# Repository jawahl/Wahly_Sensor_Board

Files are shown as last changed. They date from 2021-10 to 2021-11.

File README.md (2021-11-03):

# Wahly_Sensor_Board

**Hardware Overview**:

This board is designed around the STM32F3 microcontroller, LIS3DHTR accelerometer, and SHT30 temperature & humidity sensor. USB powered, SWD debug/programming, footprint for additional FLASH memory chip (SOIC-8), ADC/TIM pin header breakouts for external peripherals. 

Schematic and layout done in KiCAD, assembly/fab done with JLCPCB.

# Repository Definition:

**Wahly_KiCAD** - Contains all KiCAD project files. Includes schematic (with pdf viewable) and layout files.

**Firmware** - Contains all firmware files for the Wahly Sensor Board. Includes STM32CubeIDE .ioc file with all necessary driver/HAL/main C files.

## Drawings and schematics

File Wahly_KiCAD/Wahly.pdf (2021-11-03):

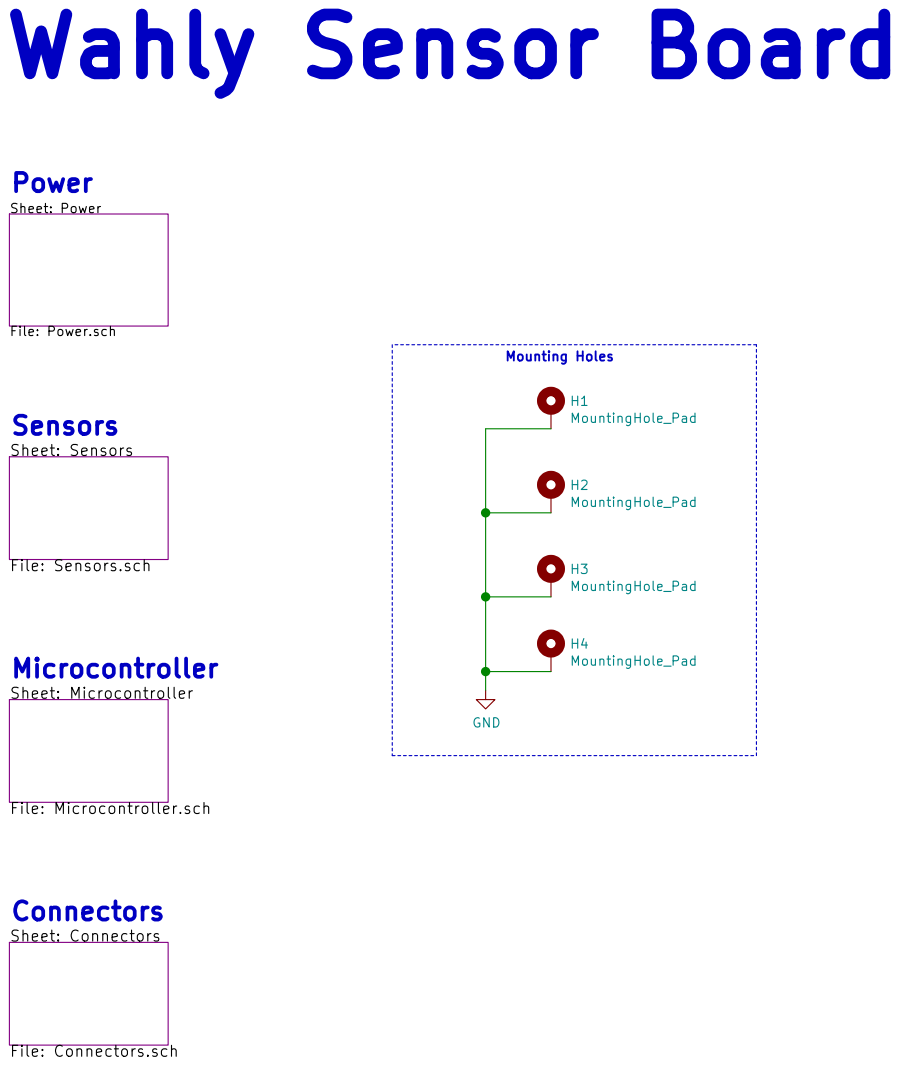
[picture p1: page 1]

Power
Sheet: Sensors File: Sensors.sch Sheet: Microcontroller File: Microcontroller.sch Sheet: Connectors File: Connectors.sch

File: Wahly.sch Sheet: /
Id: 1/5 Title: Wahly Sensor Board - STM32

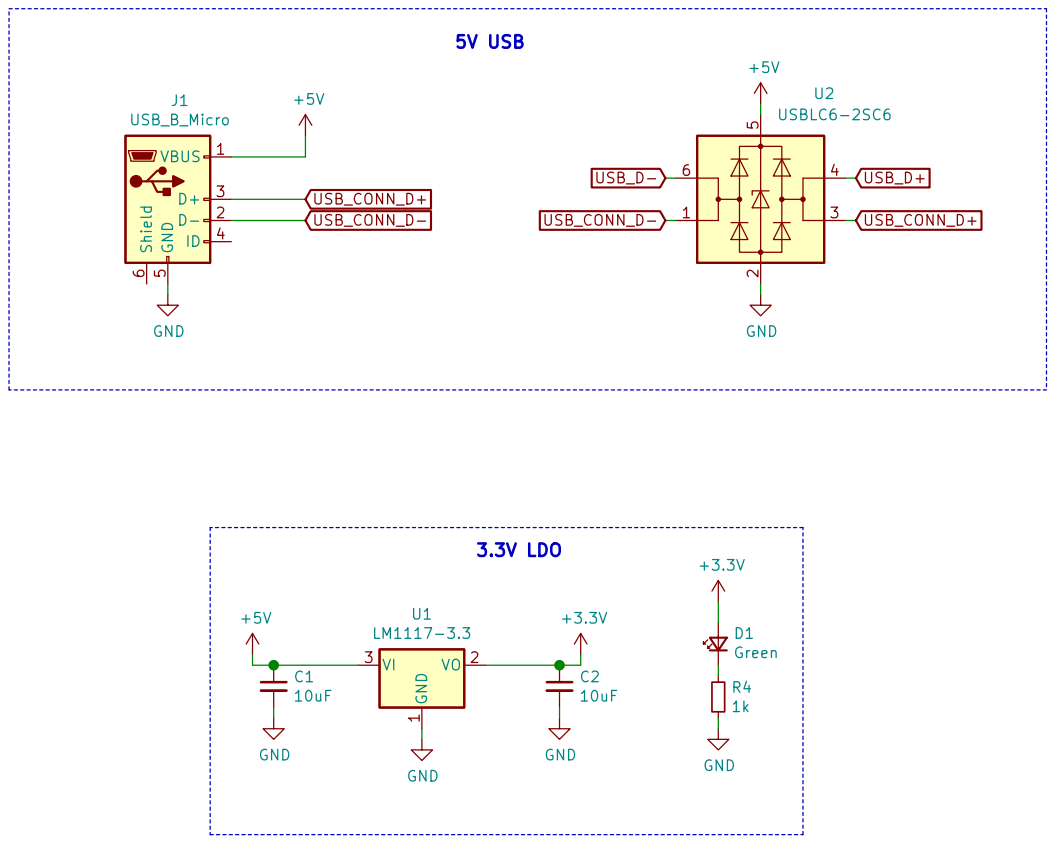
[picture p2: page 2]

File: Power.sch Sheet: /Power/ GND

Id: 2/5 Title: Wahly Sensor Board - STM32

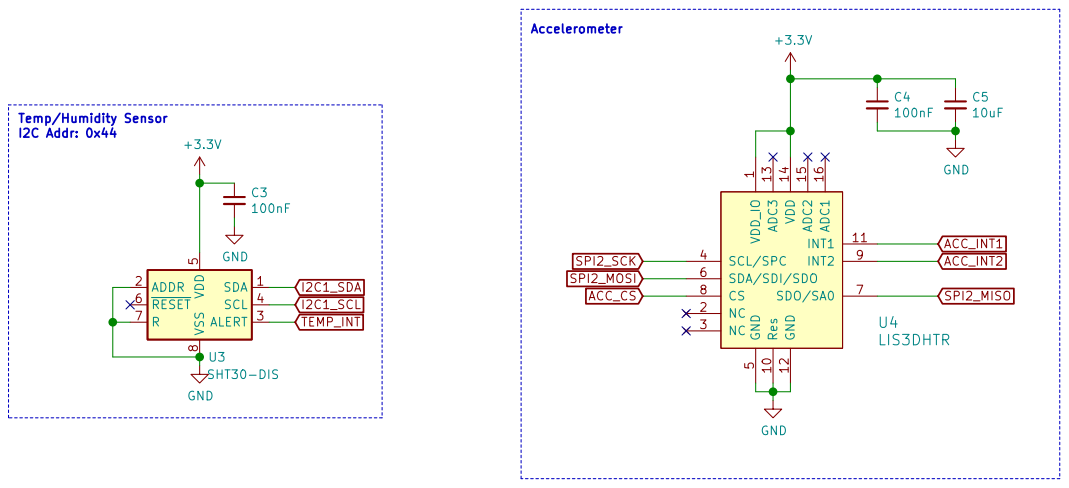
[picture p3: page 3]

1 NC 2 NC 3 SCL/SPC 4 GND

5 SDA/SDI/SDO 6 SDO/SA0 7 CS 8

File: Sensors.sch Sheet: /Sensors/ GND

Id: 3/5 Title: Wahly Sensor Board - STM32

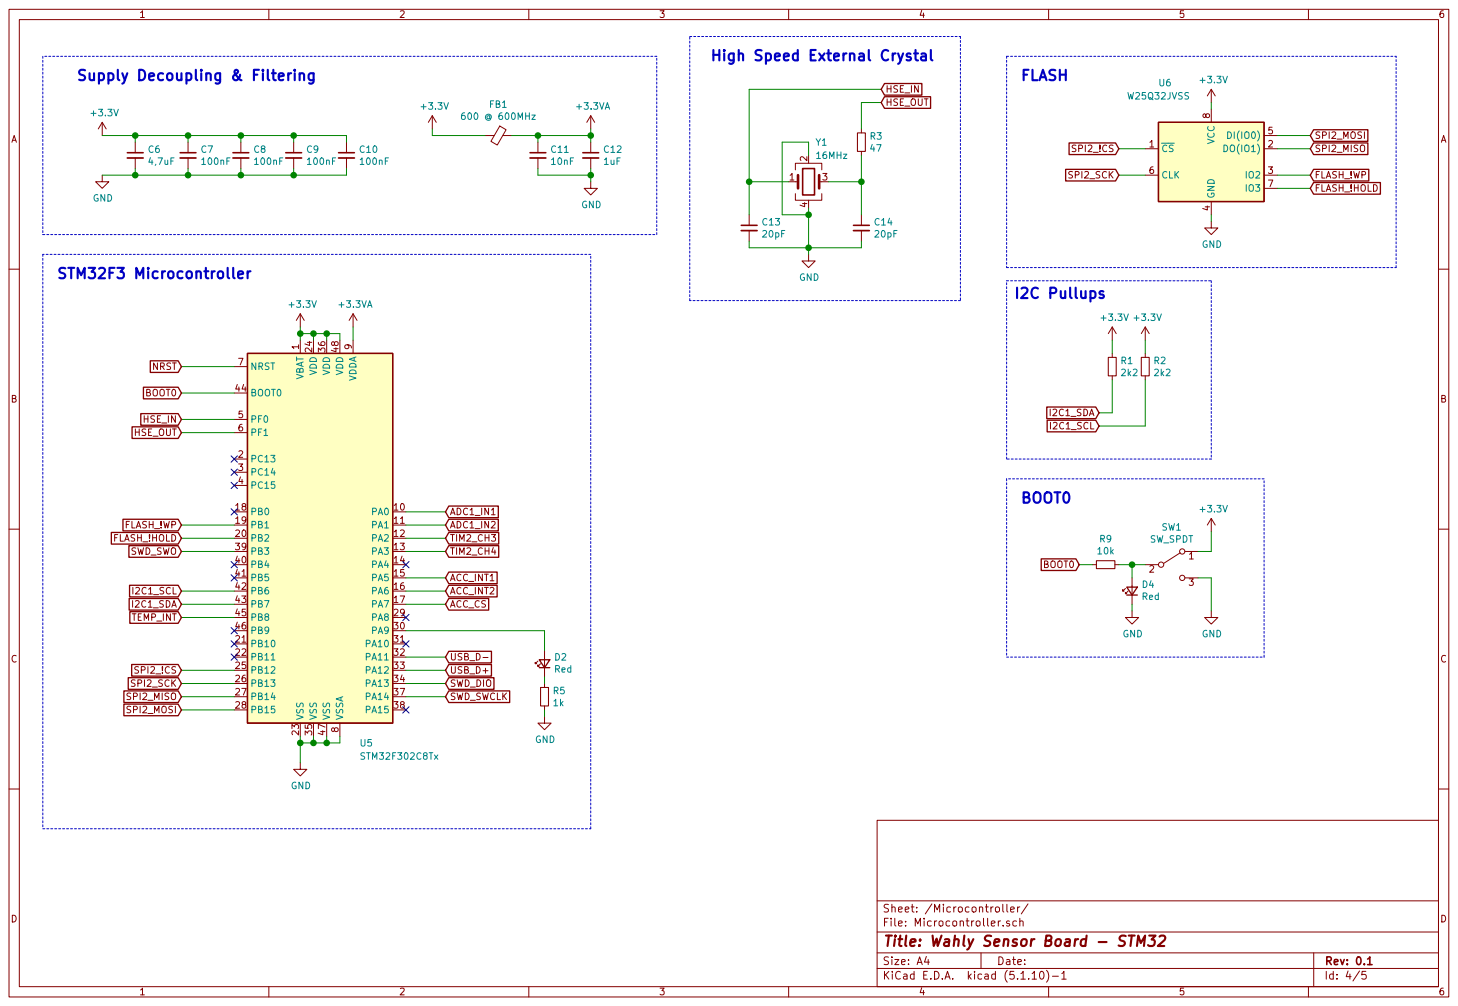
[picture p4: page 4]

High Speed External Crystal

1 VDD 24 VDD 36 VDD 48 VDDA

9 VSS 23 VSS 35 VSS 47 VSSA

File: Microcontroller.sch Sheet: /Microcontroller/
Id: 4/5 Title: Wahly Sensor Board - STM32

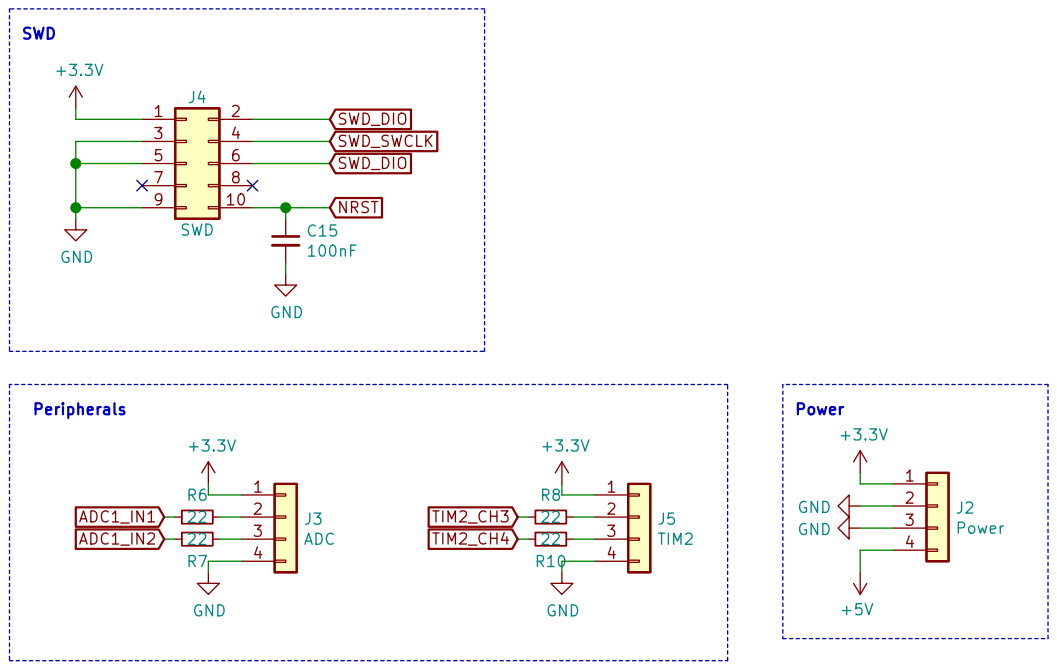
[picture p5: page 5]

File: Connectors.sch Sheet: /Connectors/
Id: 5/5 Title: Wahly Sensor Board - STM32

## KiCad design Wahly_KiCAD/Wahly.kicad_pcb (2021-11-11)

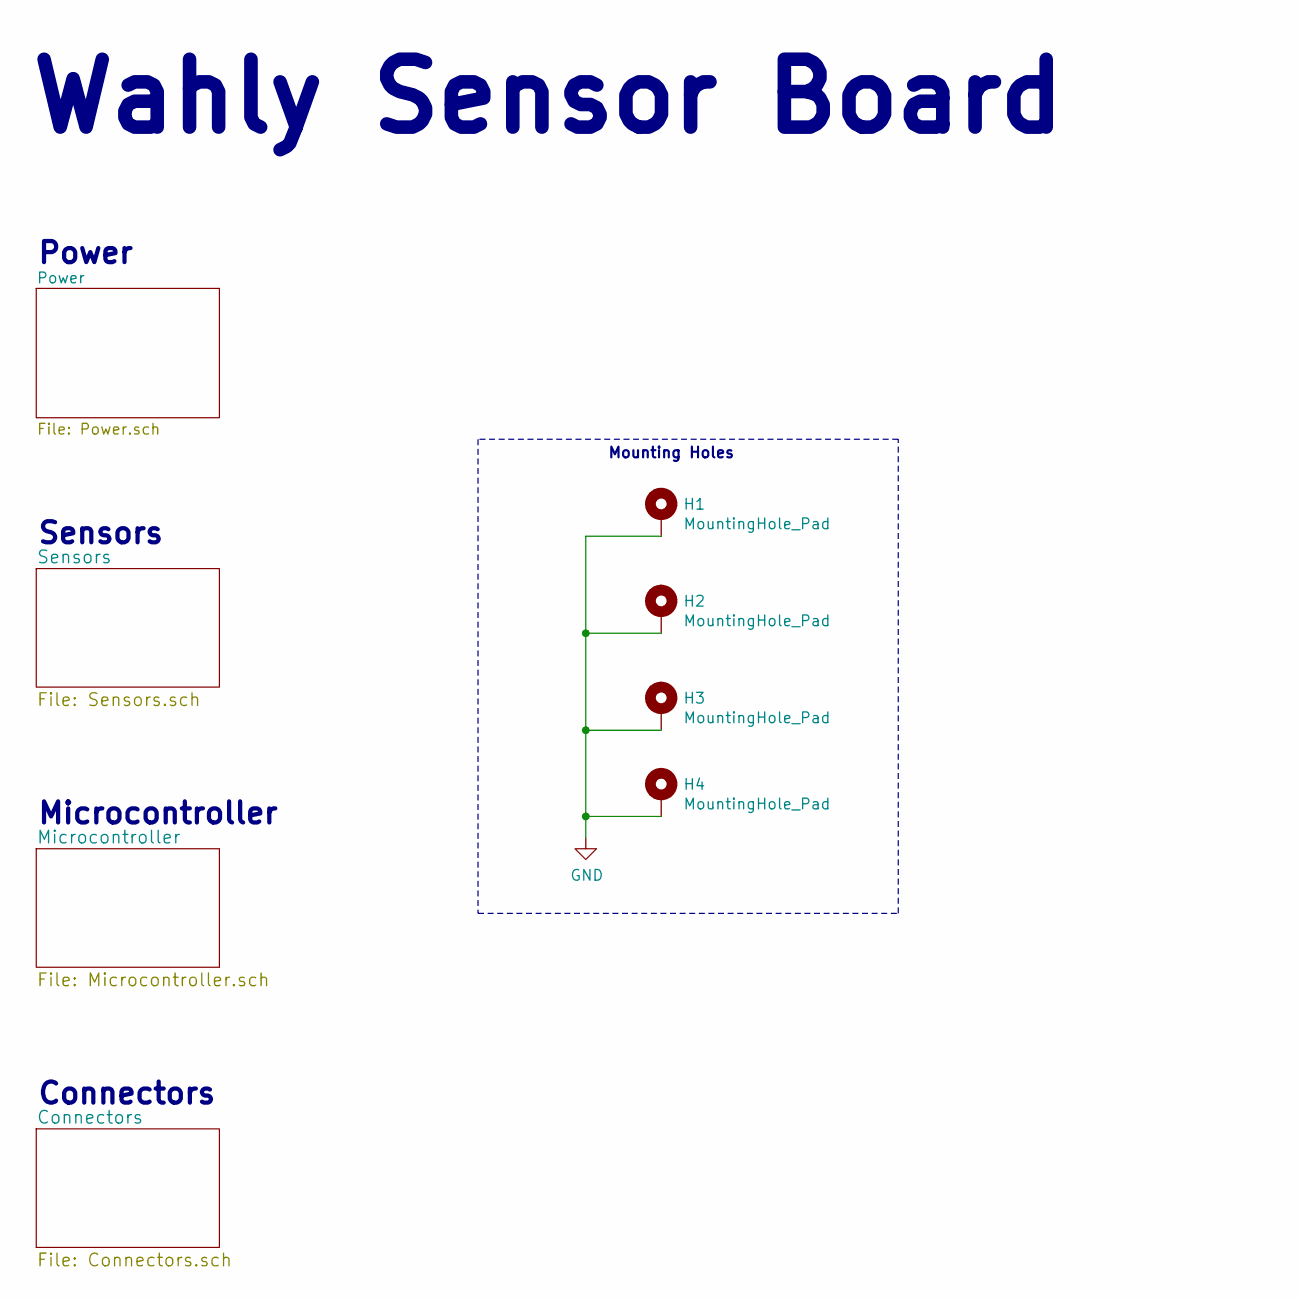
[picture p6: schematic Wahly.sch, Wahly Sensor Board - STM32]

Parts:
H1, H2, H3, H4: MountingHole_Pad; MountingHole_4.3mm_M4_Pad_Via

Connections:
GND: H1.1, H2.1, H3.1, H4.1; also elsewhere on the board

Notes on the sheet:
Wahly Sensor Board
Power
Sensors
Microcontroller
Connectors
Mounting Holes

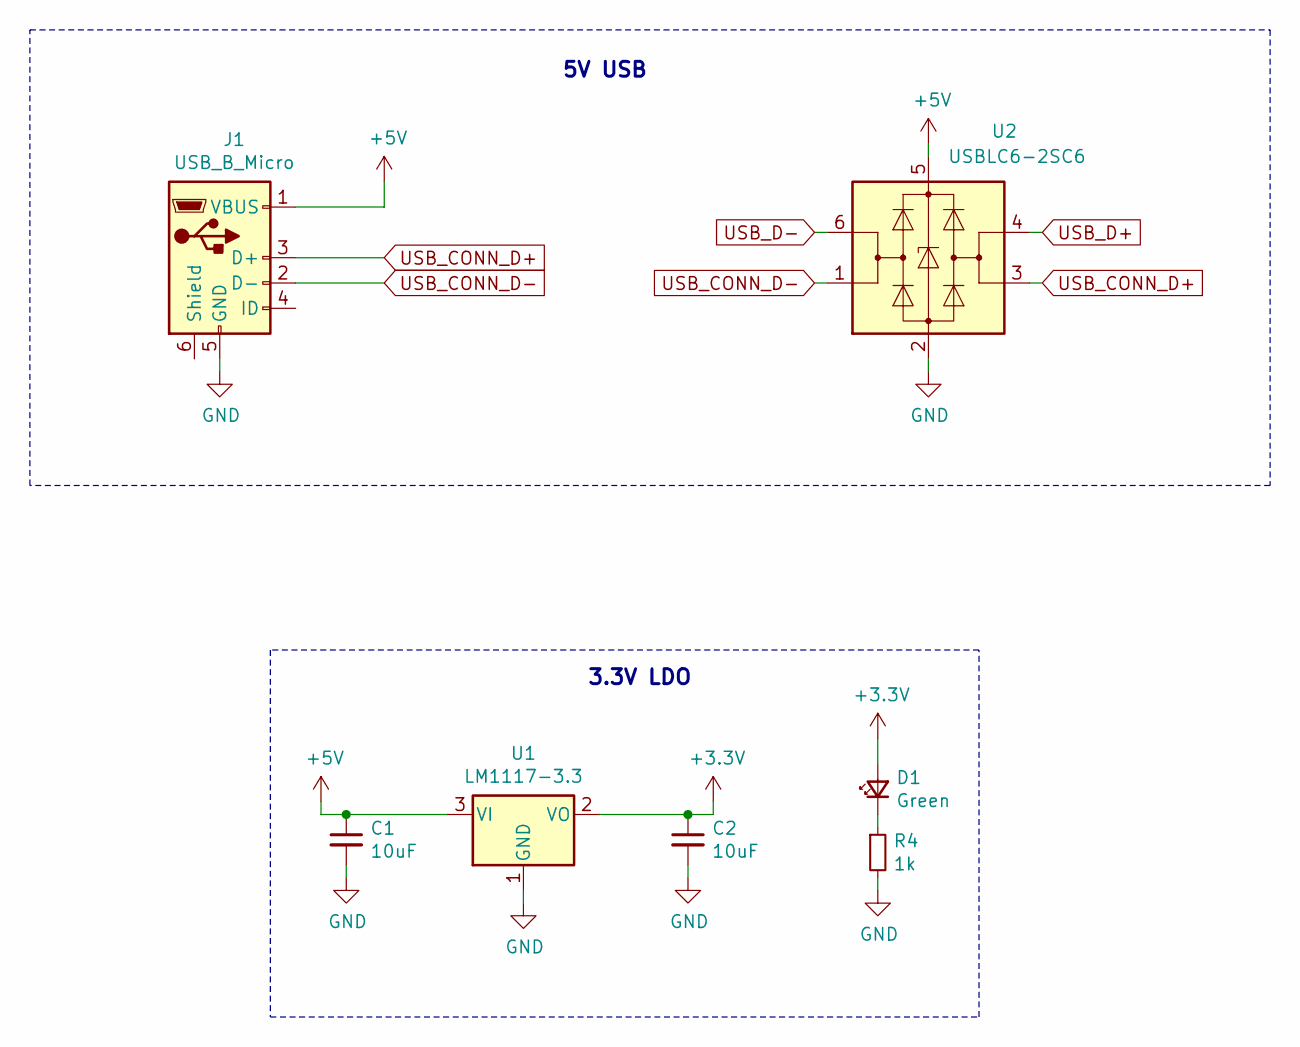
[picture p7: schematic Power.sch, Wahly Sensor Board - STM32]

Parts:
C1, C2: 10uF; C_0402_1005Metric
D1: Green; LED_0603_1608Metric
J1: USB_B_Micro; USB_Micro-B_Molex-105017-0001
R4: 1k; R_0402_1005Metric
U1: LM1117-3.3; SOT-223
U2: USBLC6-2SC6; SOT-23-6

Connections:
+3V3: C2.1, D1.2 (A), U1.2 (VO); also elsewhere on the board
+5V: C1.1, J1.1 (VBUS), U1.3 (VI), U2.5 (VBUS); also elsewhere on the board
GND: C1.2, C2.2, J1.5 (GND), R4.2, U1.1 (GND), U2.2 (GND); also elsewhere on the board
unnamed: D1.1 (K), R4.1
USB_CONN_D+: J1.3 (D+), U2.3 (I/O2)
USB_CONN_D-: J1.2 (D-), U2.1 (I/O1)
USB_D+: U2.4 (I/O2); also elsewhere on the board
USB_D-: U2.6 (I/O1); also elsewhere on the board

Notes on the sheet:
5V USB
3.3V LDO

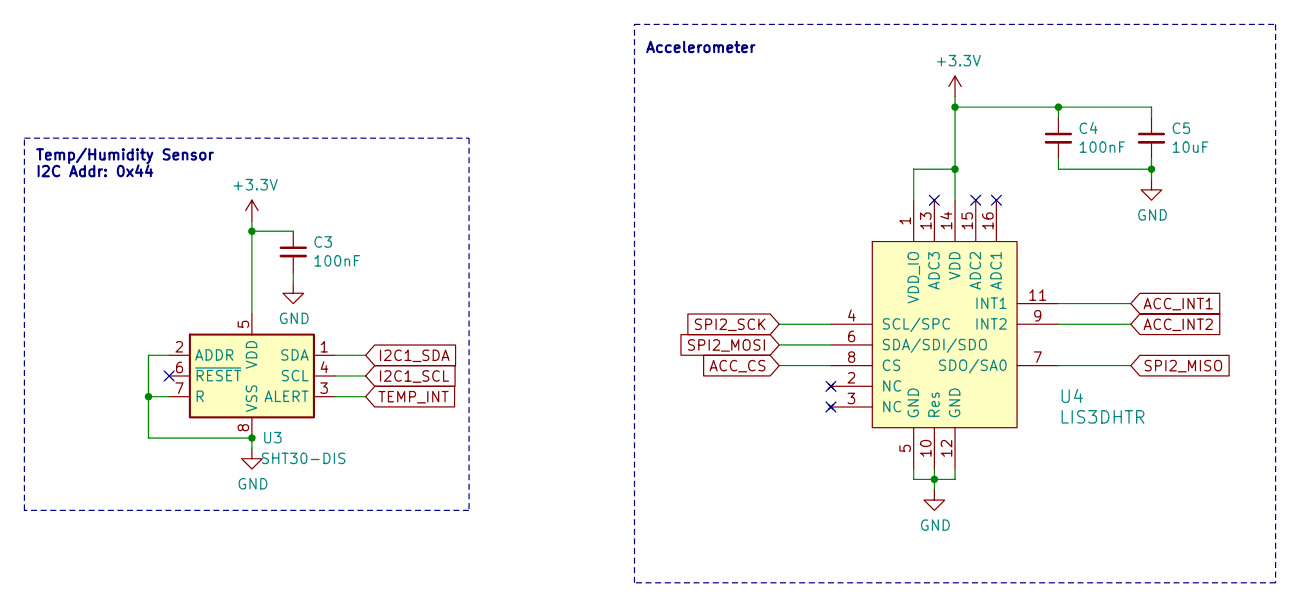
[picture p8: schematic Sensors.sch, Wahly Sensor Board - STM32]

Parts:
C3, C4: 100nF; C_0402_1005Metric
C5: 10uF; C_0402_1005Metric
U3: SHT30-DIS; Sensirion_DFN-8-1EP_2.5x2.5mm_P0.5mm_EP1.1x1.7mm
U4: LIS3DHTR; LGA-16_3x3mm_P0.5mm; MPN LIS3DHTR; Digi-Key_PN 497-10613-1-ND

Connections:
+3V3: C3.1, C4.1, C5.1, U3.5 (VDD), U4.1 (VDD_IO), U4.14 (VDD); also elsewhere on the board
ACC_CS: U4.8 (CS); also elsewhere on the board
ACC_INT1: U4.11 (INT1); also elsewhere on the board
ACC_INT2: U4.9 (INT2); also elsewhere on the board
GND: C3.2, C4.2, C5.2, U3.2 (ADDR), U3.7 (R), U3.8 (VSS), U3.9 (VSS), U4.5 (GND), U4.10 (Res), U4.12 (GND); also elsewhere on the board
I2C1_SCL: U3.4 (SCL); also elsewhere on the board
I2C1_SDA: U3.1 (SDA); also elsewhere on the board
SPI2_MISO: U4.7 (SDO/SA0); also elsewhere on the board
SPI2_MOSI: U4.6 (SDA/SDI/SDO); also elsewhere on the board
SPI2_SCK: U4.4 (SCL/SPC); also elsewhere on the board
TEMP_INT: U3.3 (ALERT); also elsewhere on the board

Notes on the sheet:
Temp/Humidity Sensor I2C Addr: 0x44
Accelerometer

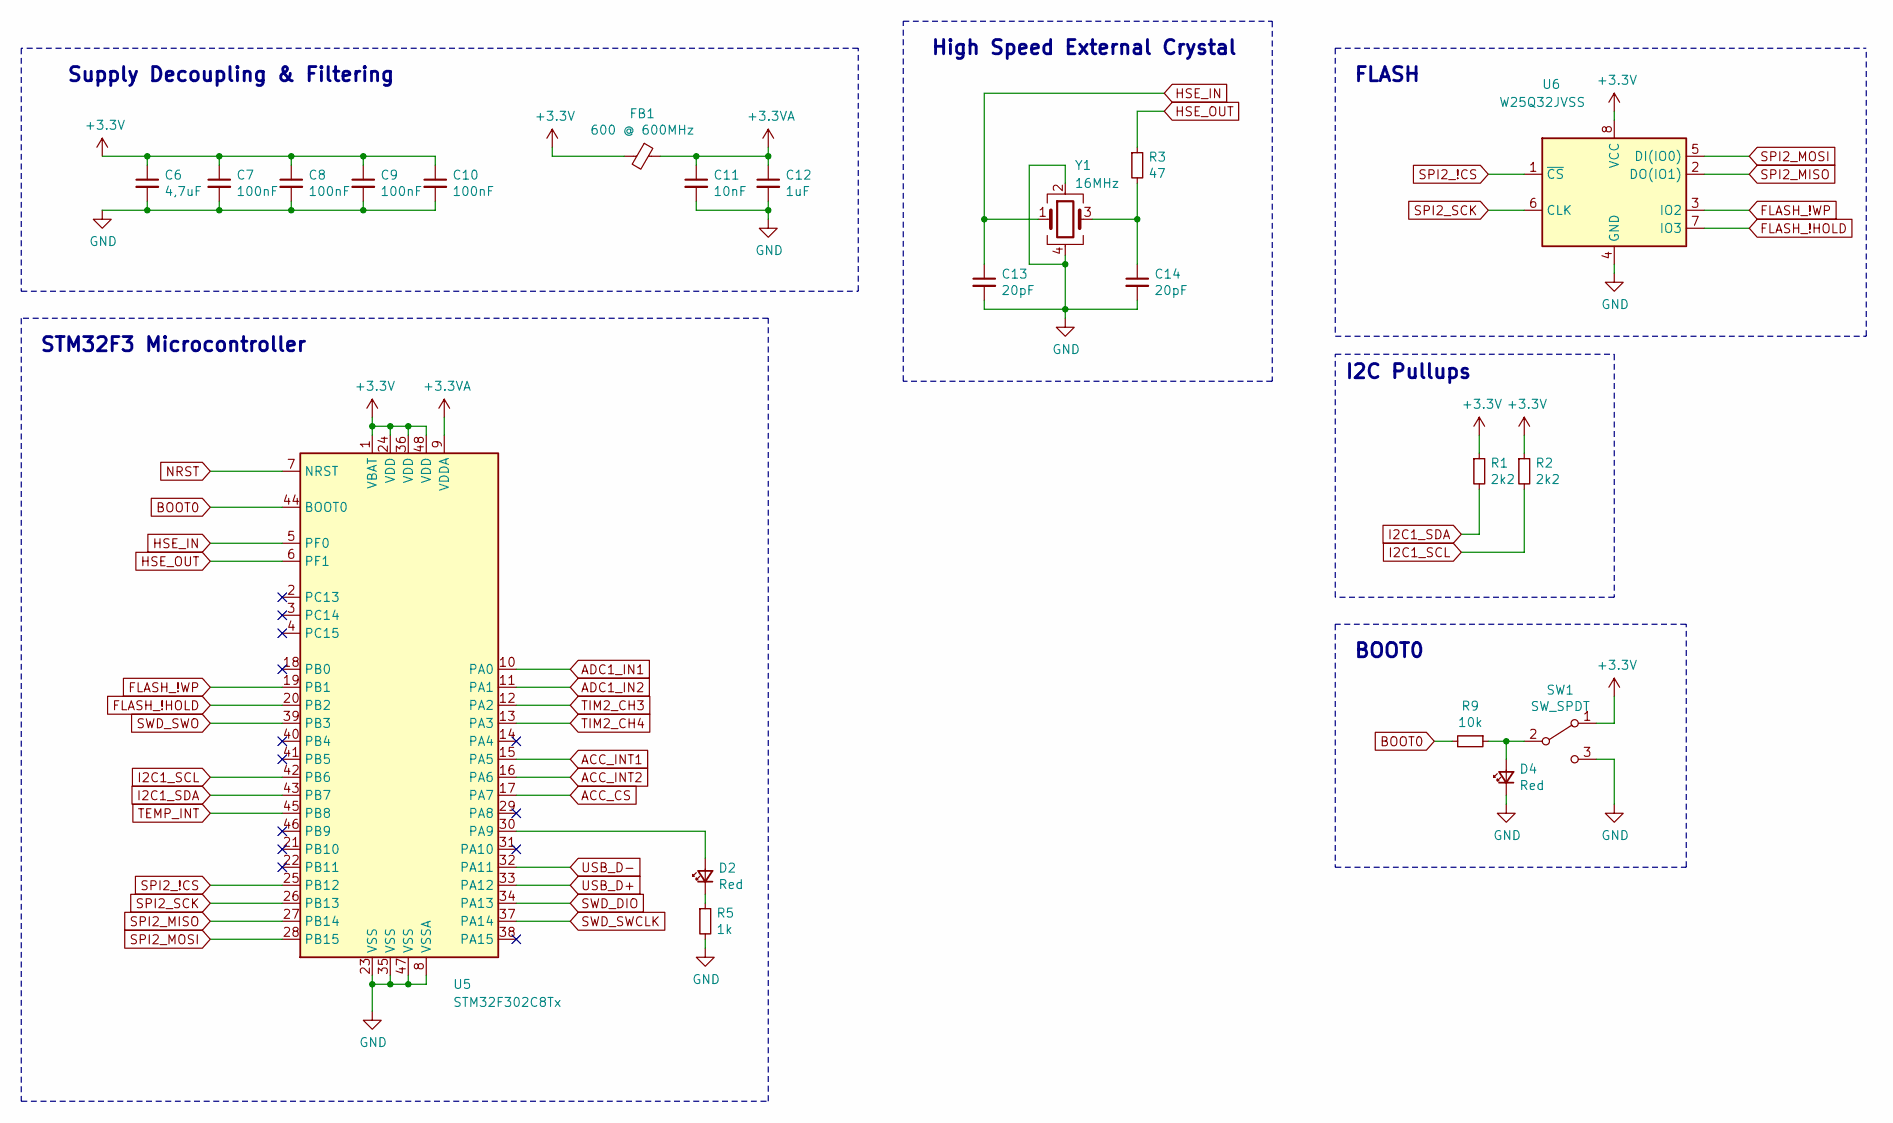
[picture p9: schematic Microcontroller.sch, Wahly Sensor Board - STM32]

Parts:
C6: 4,7uF; C_0402_1005Metric
C7, C8, C9, C10: 100nF; C_0402_1005Metric
C11: 10nF; C_0402_1005Metric
C12: 1uF; C_0402_1005Metric
C13, C14: 20pF; C_0402_1005Metric
D2, D4: Red; LED_0603_1608Metric
FB1: 600 @ 600MHz; L_0603_1608Metric
R1, R2: 2k2; R_0603_1608Metric
R3: 47; R_0402_1005Metric
R5: 1k; R_0402_1005Metric
R9: 10k; R_0603_1608Metric
SW1: SW_SPDT; SW_SPDT_PCM12
U5: STM32F302C8Tx; LQFP-48_7x7mm_P0.5mm
U6: W25Q32JVSS; SOIC-8_5.23x5.23mm_P1.27mm
Y1: 16MHz; Crystal_SMD_TXC_7M-4Pin_3.2x2.5mm

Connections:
+3.3VA: C11.1, C12.1, FB1.1, U5.9 (VDDA)
+3V3: C6.1, C7.1, C8.1, C9.1, C10.1, FB1.2, R1.1, R2.1, SW1.1 (A), U5.1 (VBAT), U5.24 (VDD), U5.36 (VDD), U5.48 (VDD), U6.8 (VCC); also elsewhere on the board
ACC_CS: U5.17 (PA7); also elsewhere on the board
ACC_INT1: U5.15 (PA5); also elsewhere on the board
ACC_INT2: U5.16 (PA6); also elsewhere on the board
ADC1_IN1: U5.10 (PA0); also elsewhere on the board
ADC1_IN2: U5.11 (PA1); also elsewhere on the board
BOOT0: R9.2, U5.44 (BOOT0)
FLASH_!HOLD: U5.20 (PB2), U6.7 (IO3)
FLASH_!WP: U5.19 (PB1), U6.3 (IO2)
GND: C6.2, C7.2, C8.2, C9.2, C10.2, C11.2, C12.2, C13.2, C14.2, D4.1 (K), R5.2, SW1.3 (C), U5.8 (VSSA), U5.23 (VSS), U5.35 (VSS), U5.47 (VSS), U6.4 (GND), Y1.2, Y1.4; also elsewhere on the board
HSE_IN: C13.1, U5.5 (PF0), Y1.1
HSE_OUT: R3.1, U5.6 (PF1)
I2C1_SCL: R2.2, U5.42 (PB6); also elsewhere on the board
I2C1_SDA: R1.2, U5.43 (PB7); also elsewhere on the board
NRST: U5.7 (NRST); also elsewhere on the board
unnamed: C14.1, R3.2, Y1.3
unnamed: D2.1 (K), R5.1
unnamed: D2.2 (A), U5.30 (PA9)
unnamed: D4.2 (A), R9.1, SW1.2 (B)
SPI2_!CS: U5.25 (PB12), U6.1 (~CS)
SPI2_MISO: U5.27 (PB14), U6.2 (DO(IO1)); also elsewhere on the board
SPI2_MOSI: U5.28 (PB15), U6.5 (DI(IO0)); also elsewhere on the board
SPI2_SCK: U5.26 (PB13), U6.6 (CLK); also elsewhere on the board
SWD_DIO: U5.34 (PA13); also elsewhere on the board
SWD_SWCLK: U5.37 (PA14); also elsewhere on the board
SWD_SWO: U5.39 (PB3); also elsewhere on the board
TEMP_INT: U5.45 (PB8); also elsewhere on the board
TIM2_CH3: U5.12 (PA2); also elsewhere on the board
TIM2_CH4: U5.13 (PA3); also elsewhere on the board
USB_D+: U5.33 (PA12); also elsewhere on the board
USB_D-: U5.32 (PA11); also elsewhere on the board

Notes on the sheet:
Supply Decoupling & Filtering
High Speed External Crystal
I2C Pullups
STM32F3 Microcontroller
BOOT0
FLASH

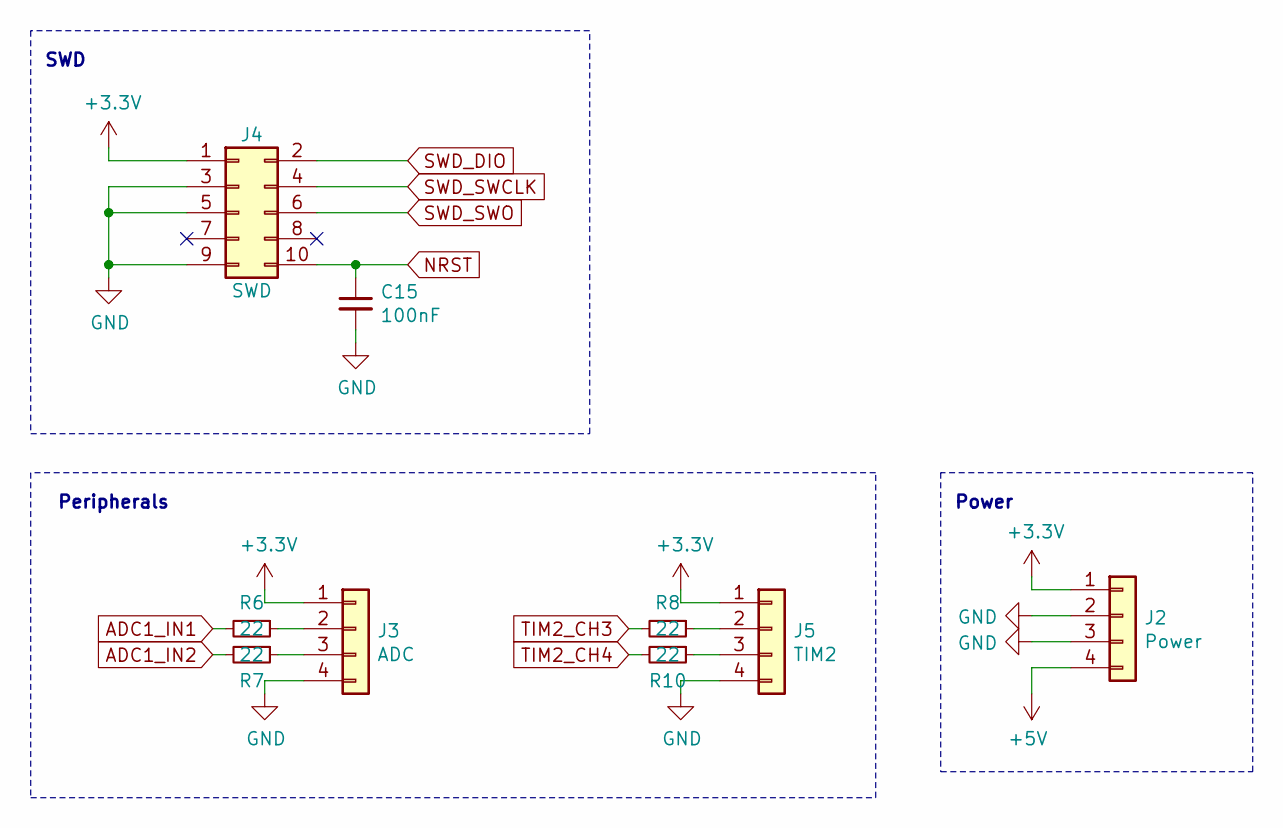
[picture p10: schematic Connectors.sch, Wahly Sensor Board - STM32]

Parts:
C15: 100nF; C_0402_1005Metric
J2: Power; PinHeader_1x04_P2.54mm_Vertical
J3: ADC; PinHeader_1x04_P2.54mm_Vertical
J4: SWD; PinHeader_2x05_P1.27mm_Vertical_SMD
J5: TIM2; PinHeader_1x04_P2.54mm_Vertical
R6, R7, R8, R10: 22; R_0603_1608Metric

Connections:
+3V3: J2.1, J3.1, J4.1, J5.1; also elsewhere on the board
+5V: J2.4; also elsewhere on the board
ADC1_IN1: R6.2; also elsewhere on the board
ADC1_IN2: R7.2; also elsewhere on the board
GND: C15.2, J2.2, J2.3, J3.4, J4.3, J4.5, J4.9, J5.4; also elsewhere on the board
NRST: C15.1, J4.10; also elsewhere on the board
unnamed: J3.2, R6.1
unnamed: J3.3, R7.1
unnamed: J5.2, R8.1
unnamed: J5.3, R10.1
SWD_DIO: J4.2; also elsewhere on the board
SWD_SWCLK: J4.4; also elsewhere on the board
SWD_SWO: J4.6; also elsewhere on the board
TIM2_CH3: R8.2; also elsewhere on the board
TIM2_CH4: R10.2; also elsewhere on the board

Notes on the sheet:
Peripherals
Power
SWD

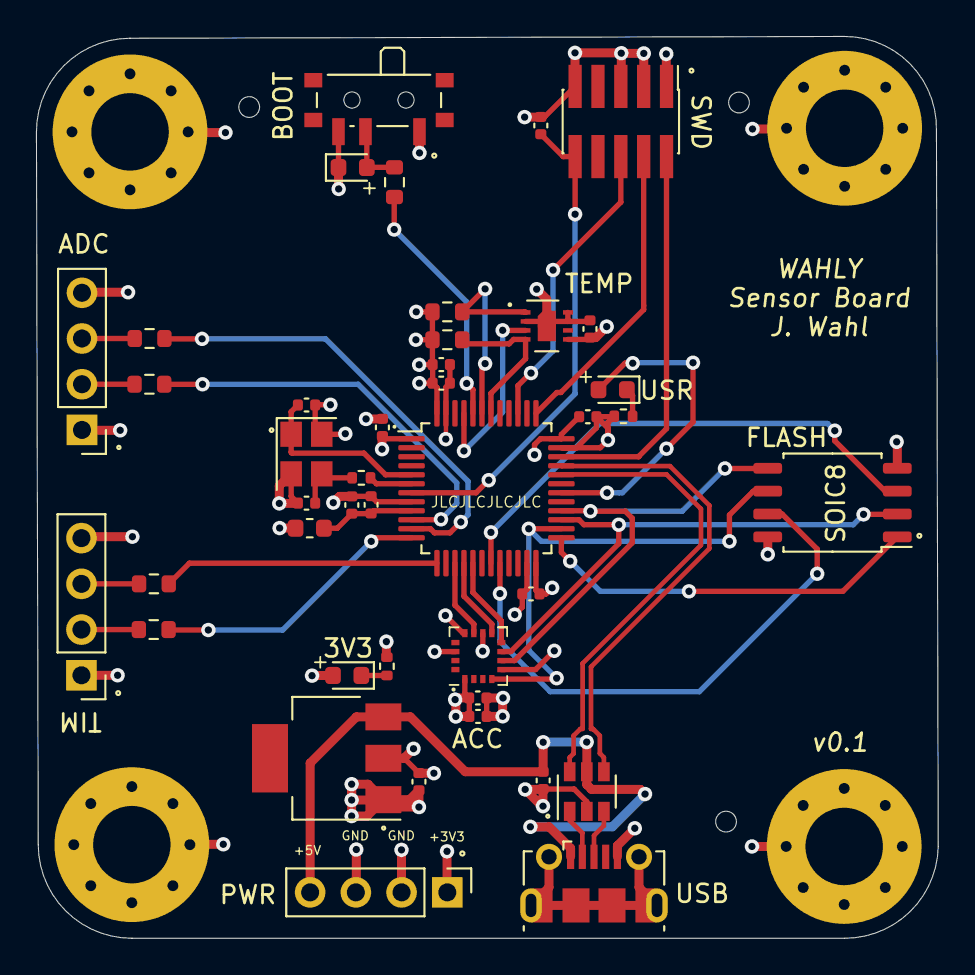
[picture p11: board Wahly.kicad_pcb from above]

Board: 4 copper layers, 50.1 x 50.1 mm, 46 parts (0 on the bottom side), 40 nets.

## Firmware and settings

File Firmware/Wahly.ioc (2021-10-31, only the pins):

Mcu.UserName=STM32F302C8Tx
PA11.Signal=USB_DM
PA12.Signal=USB_DP
PA13.Signal=SYS_JTMS-SWDIO
PA14.Signal=SYS_JTCK-SWCLK
PA15.Signal=I2C1_SCL
PB13.Signal=SPI2_SCK
PB14.Signal=SPI2_MISO
PB15.Signal=SPI2_MOSI
PB7.Signal=I2C1_SDA
PF0-OSC_IN.Signal=RCC_OSC_IN
PF1-OSC_OUT.Signal=RCC_OSC_OUT

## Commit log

2021-10-31 initial upload of files
    [Connectors.sch, Microcontroller.sch, Power.sch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]
2021-10-31 save updates
    [Connectors.sch]
2021-11-03 pdf schematic
    [Connectors.sch, Microcontroller.sch, Power.sch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]
2021-11-11 Silkscreen & DRC
    [Connectors.sch, Wahly.kicad_pcb]
